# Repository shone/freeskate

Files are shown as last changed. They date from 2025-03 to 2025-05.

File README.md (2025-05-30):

# Freeskate

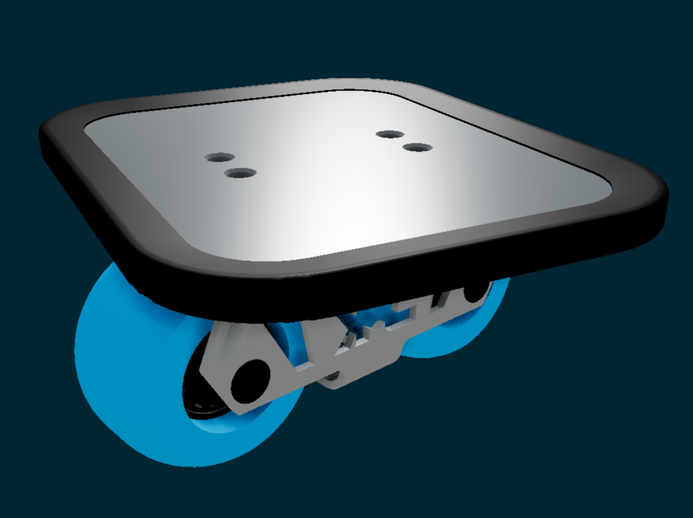
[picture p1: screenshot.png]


A [FreeCAD](https://www.freecad.org) model of a [JMK](https://www.jmkride.com) [Freeskate](https://en.wikipedia.org/wiki/Freeskates). The 3D model is viewable at [shone.dev/freeskate](https://shone.dev/freeskate)

## Holster

To get rail length: `App.getDocument("freeskate").getObjectsByLabel("rails-shape-binder")[0].Shape.Length`

| Name | Length | Bend | Mandril diameter | Actual diameter |
|---|---|---|---|---|
| Wheel guard |  94.25mm | 180deg | | 60mm |
| Along truck left edge | 100mm | | | |
| Bend back | 15.7mm | 180deg | 9mm | 10mm |
| Back along truck left edge  | 153mm | | | |
| Bend around deck | 30.6mm | 180deg | 18mm | 19.5mm |
| Along deck | 112.25mm | | | |
| Bend across deck | 15.3mm | 90deg | 18mm | 19.5mm |
| Across deck |  40.50mm | | | |
| Bend back along deck | 15.3mm | 90deg | 18mm | 19.5mm |
| Back along deck | 112.25mm | | | |
| Bend around deck | 30.6mm | 180deg | 18mm | 19.5mm |
| Along truck right edge | 153mm | | | |
| Bend back | 15.7mm | 180deg | 9mm | 10mm |
| Back along truck right edge | 30mm | | | |
| Bend catch into truck | 2mm |  23.75deg | 9mm | 10mm |
| Ramp into truck |  35.57mm | | | |
| Bend back out of truck | 9.93mm | 113.75deg | 9mm | 10mm |
| Catch edge | 12mm | | | |
| Catch handle angle | 4.36mm | 50deg | 9mm | 10mm |
| Catch handle | 18mm | | | |

## Rod bending

6mm stainless steel rod, bent 180 degrees around an 18mm diameter mandril resulted in an actual inner bend diameter of 19.5mm (outer diameter ~32mm). The actual bend diameter is larger than the mandril due to spring-back of the stainless steel material. Also, to acheive a 180 degree bend the rod must be bend back onto itself so that it touches and then bent even a bit further.

| Material | Bend | Mandril diameter | Actual bend diameter (inner) | Actual bend diameter (rod center) |
| --- | --- | --- | --- | --- |
| 6mm Stainless steel rod | 180 deg | 18mm | 19.5mm | 25.5mm |
| 6mm Stainless steel rod | 180 deg | 9mm | 10.0mm | 16.0mm |

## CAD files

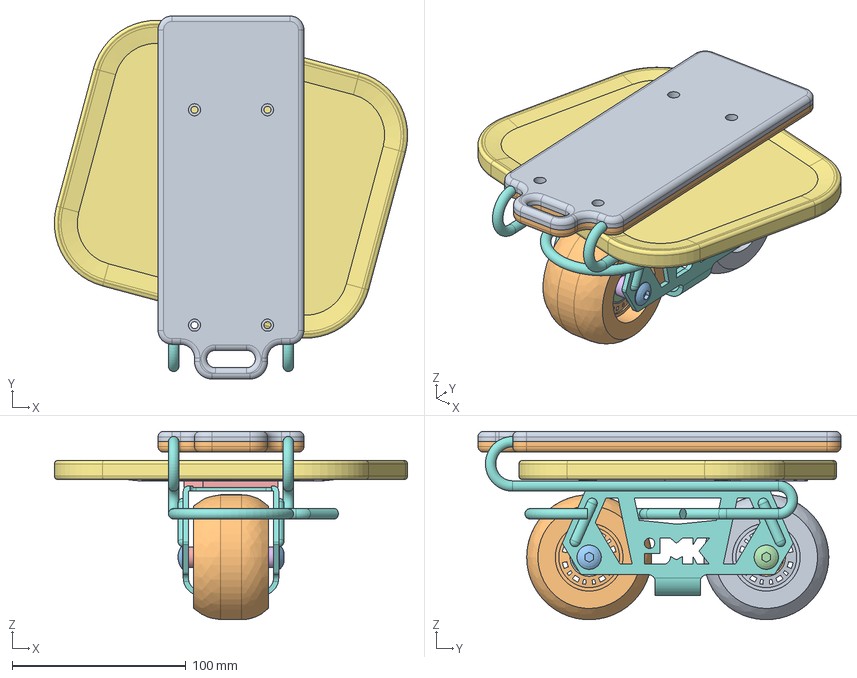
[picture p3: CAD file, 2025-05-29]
freeskate.FCStd
203.4 x 209.0 x 108.5 mm
wheel-back
wheel-front
axle-front
axle-back
shock-absorber
deck
edge-guard
chassis
bearing-outer-front-left
bearing-outer-back-left
bearing-outer-back-right
bearing-outer-front-right
washer
washer (Mirror #7)
washer (Mirror #8)
washer (Mirror #9)
wheel-inner-back
wheel-inner-front
bearing-inner-back-left
bearing-inner-front-left
bearing-inner-front-right
bearing-inner-back-right
grip-tape
rails
bottom
top

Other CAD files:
freeskate.blend

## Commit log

2022-11-06 Initial commit with Freecad file: has chassis, wheels, plate and beginnings of holster
    [freeskate.FCStd]
2023-06-29 Add index.html with GLTF viewer adapted from https://gltf-viewer.donmccurdy.com/
    Also add grip-tape inset
    [freeskate.FCStd]
2023-06-30 Fix missing components in gltf and set custom colors/materials
    - Re-export gltf to ensure mirrored components aren't missing.
    - Set custom materials for each component.
    - Add freeskate logo and set as favicon.
    [freeskate.FCStd]
2023-06-30 Add taper to plate ribs
    [freeskate.FCStd]
2024-04-15 Create initial holster v2: single-piece 3D print with locking arms. Also add detail to freeskate, including edge-guard
    [freeskate.FCStd]
2024-04-17 Improvements to holster v2: pre-tension arms, wider radius in arm bend cut, tweak tolerances..
    [freeskate.FCStd]
2024-04-20 Make color selector menus for wheels and edge-guards, + fix duplicate meshes
2024-04-20 Add fullscreen button
2024-04-21 Holster: add fin to arms that can be filed off to adjust bendiness, add hole for belt, fillet bottom, minor tweaks
    [freeskate.FCStd]
2024-05-19 Fix deck orientation, other fixes..
    - Rename "plate" to "deck" to match JMK terminology.
    - More accurate deck ribbing geometry.
    - Disable text selection in webapp.
    [freeskate.FCStd]
2024-06-23 Add deck bolt-holes
    [freeskate.FCStd]
2024-06-23 Add Blender file
    [freeskate.blend]
2024-06-30 Solarized UI styling, wheel/edge-guard icons, 'none' option for wheels/edge-guard
2024-06-30 Work on holster CAD: spiral spring, pin axle, catch arm details
    [freeskate.FCStd]
2024-07-22 Some updates to holster CAD
    [freeskate.FCStd]
2024-07-22 Add to readme: how to get holster rail length using Python console in FreeCAD
2024-07-22 More work on holster: add tolerance to rail holes, pre-tension catch, strengthening and more..
    [freeskate.FCStd]
2024-08-04 Add holster rail bend calculations and add mandrels for 3d printing
    [freeskate.FCStd]
2024-08-09 Holster: add tolerance to base rail bend groove
    [freeskate.FCStd]
2025-01-26 Add griptape and make color/visibility selectable
    [freeskate.FCStd]
2025-02-02 Cleanup/rename Freecad objects
    [freeskate.FCStd]
2025-02-12 Implement fixed turntable camera with kinetic scrolling
2025-04-06 Remove old holster designs from FreeCAD file
    [freeskate.FCStd]
2025-04-06 Fix FreeCAD python snippet to get rail length in readme
2025-04-13 Start on holster base plate design using CNC milled wood
    [freeskate.FCStd]
2025-04-14 Remove holster base slots for belt, fillet edges and make handle (in preparation for MOLLE system)
    [freeskate.FCStd]
2025-04-19 Fix CNC'd top/bottom plate geometry
    [freeskate.FCStd]
2025-04-20 Add hex bolt cavities into top/bottom plates
    [freeskate.FCStd]
2025-04-21 Make catch out of rail bends, add base bolt cavities
    [freeskate.FCStd]
2025-04-27 Add metal bender
    [freeskate.FCStd]
2025-04-27 Add detail to MOLLE clip
    [freeskate.FCStd]
2025-05-29 Change holster rail bends to actual known tested/achievable diameters and add info in readme
    [freeskate.FCStd]
2025-05-30 Add new holster rail bend segment parameters to readme
